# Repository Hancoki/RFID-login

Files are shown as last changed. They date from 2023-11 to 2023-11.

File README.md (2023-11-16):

# RFID-login

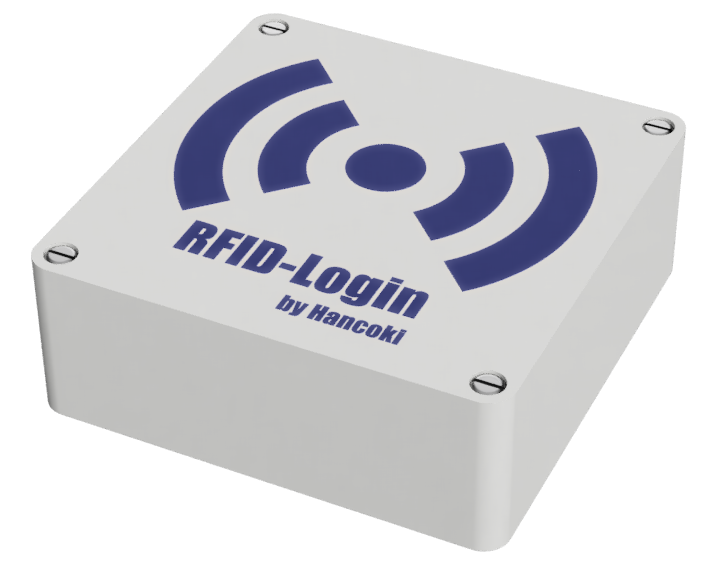
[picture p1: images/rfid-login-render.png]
RFID login render


## Description

This is a RFID login device based on the microcontroller [Sparkfun Pro Micro](https://github.com/sparkfun/Pro_Micro). It allows easy to type in your login credentials in same way as your keyboard does. But it seems a little bit smarter.

In first step I developed this device as a prototype on a breadboard. For the device I used the following components.

### Bill of material

- SparkFun Pro Micro 3.3V/8MHz microcontroller
- RFID MFRC522 reader & IC card
- circuit board size 70mm x 50mm
- USB mini cable (USB-A male/USB-B male) ~1m
- resistors 3x 200Ohm, 1x 100Ohm
- RGB led
- switch
- piezo buzzer

### Wiring

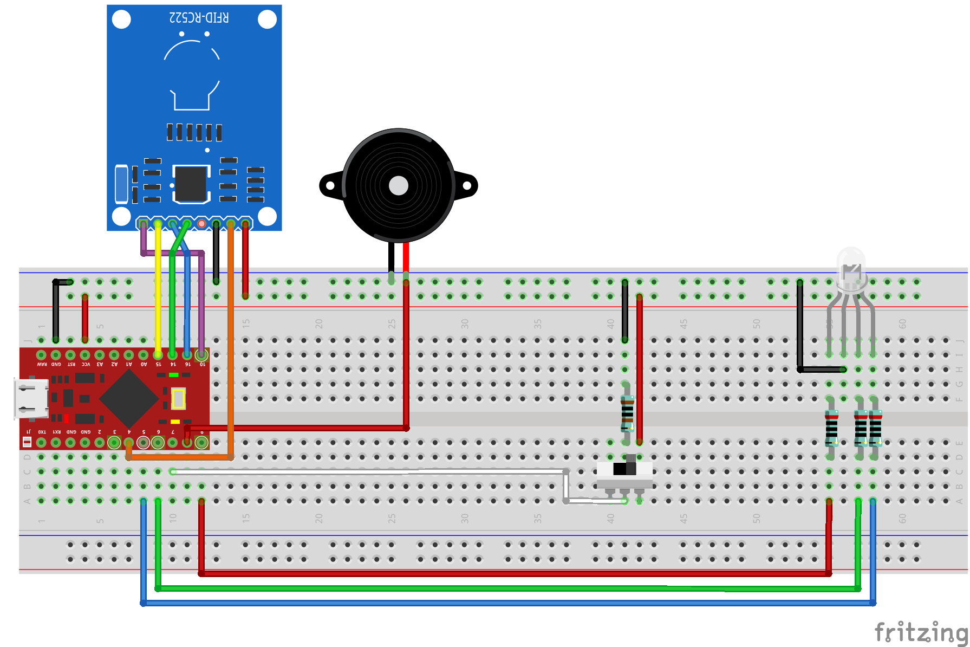
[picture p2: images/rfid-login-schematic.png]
RFID login schematic


As you can see in schematic above I wired the pins of microcontroller as follows:

Pin | Function      | Pin   | Function
--- | --------      | ---   | --------
4   | RST (RFID)    | 10    | SDA (RFID)
5   | LED (blue)    | 14    | MISO (RFID)
6   | LED (green)   | 15    | SCK (RFID)
7   | switch        | 16    | MOSI (RFID)
8   | buzzer        | GND   | GND
9   | LED (red)     | VCC   | 3.3V (RFID)

### Programming

For programming the Pro Micro I used [PlatformIO](https://github.com/platformio/platformio-core) inside of [VS CODE](https://github.com/microsoft/vscode).

Included libraries:
- [Keyboard library for Arduino](https://www.arduino.cc/reference/en/language/functions/usb/keyboard/)
- [Arduino library for MFRC522 by miguelbalboa](https://github.com/miguelbalboa/rfid)

## What comes next?

For a future version of my RFID login device I plan to decrement the size of case and develop a custom circuit board for it. Also a possibility to program the device instant without compiling the code again and again would be very nice.

If you have any questions or ideas for improvement, please let me know and write an issue.

Thanks for your participation!

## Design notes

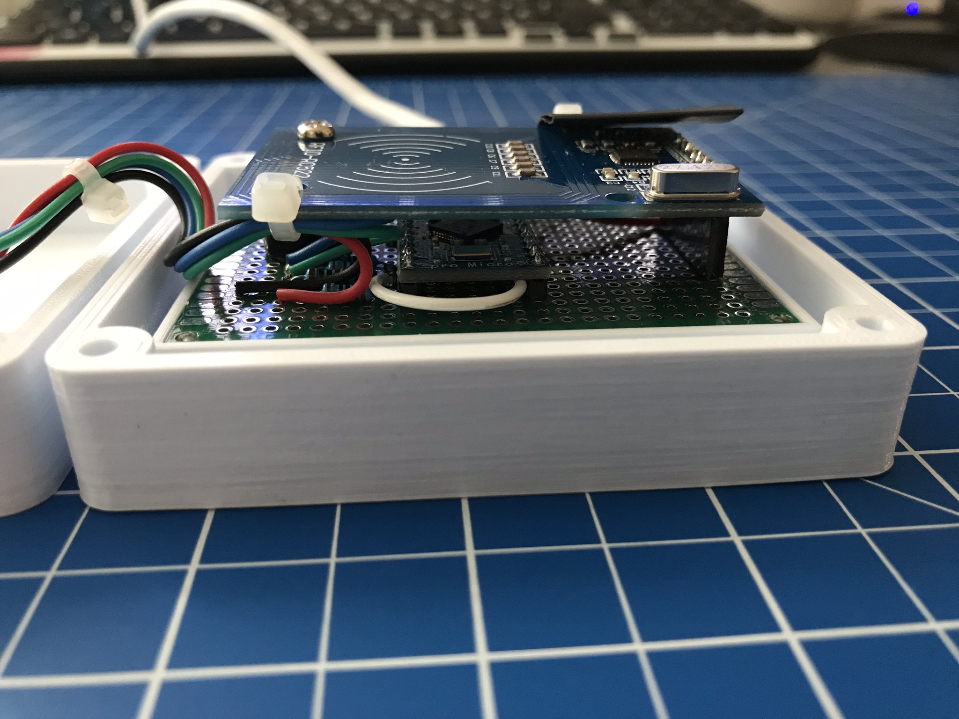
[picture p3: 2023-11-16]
images/rfid-login-prototype-sideview.jpg

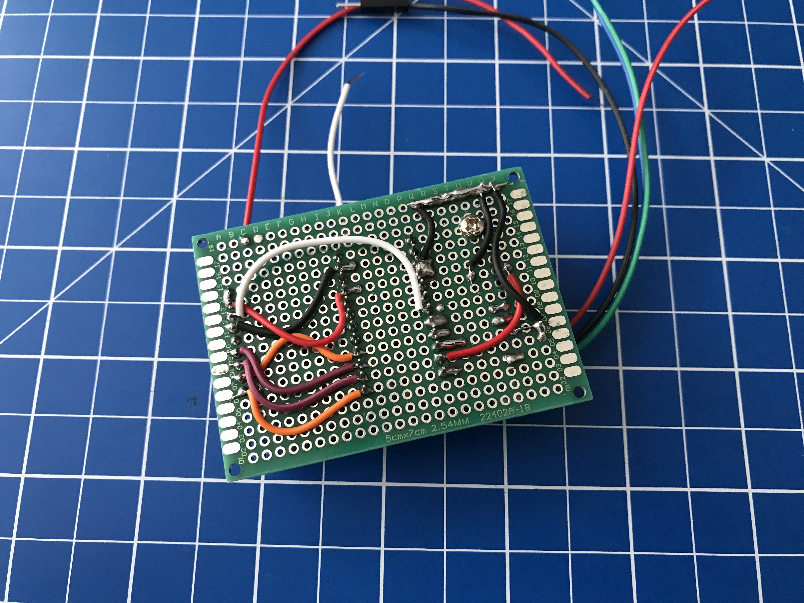
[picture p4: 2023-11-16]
images/rfid-login-prototype-circuit-board.jpg

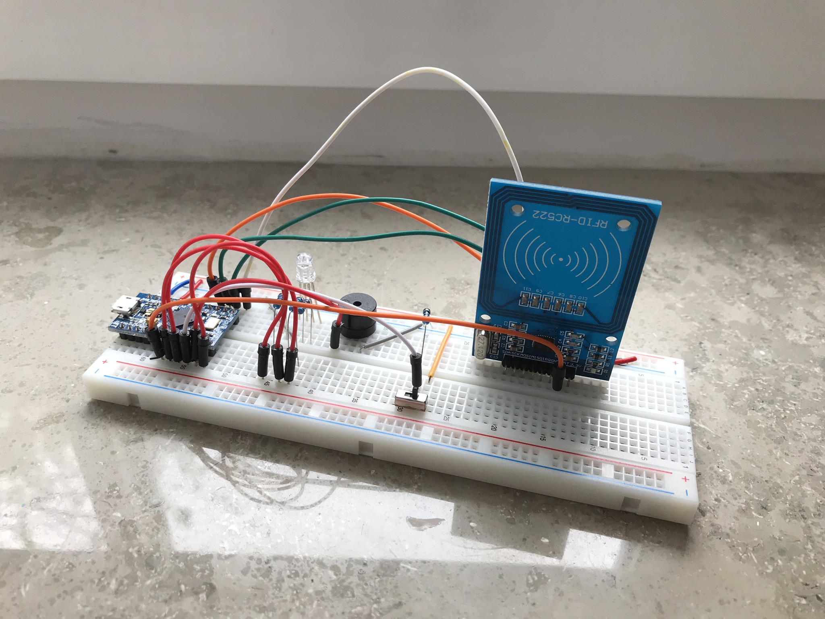
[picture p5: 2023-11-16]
images/rfid-login-prototype-breadboard.jpg

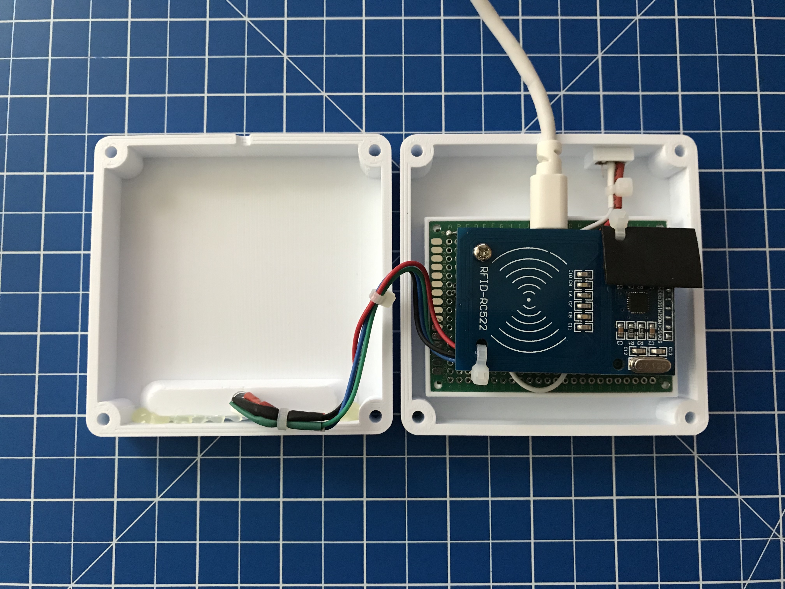
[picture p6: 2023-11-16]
images/rfid-login-prototype-final.jpg

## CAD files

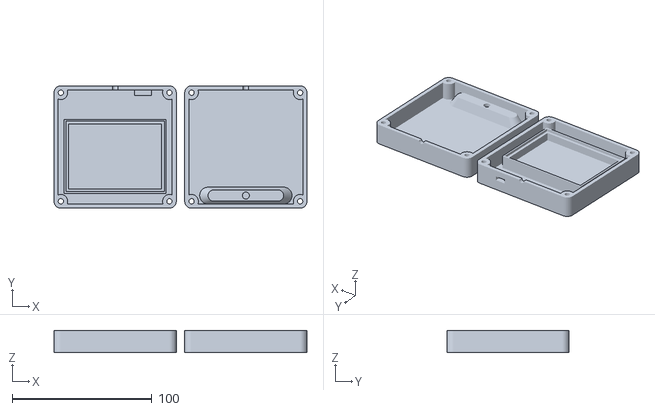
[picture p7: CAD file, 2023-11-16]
3d-files/case-complete.stl
180.8 x 87.4 x 16.0

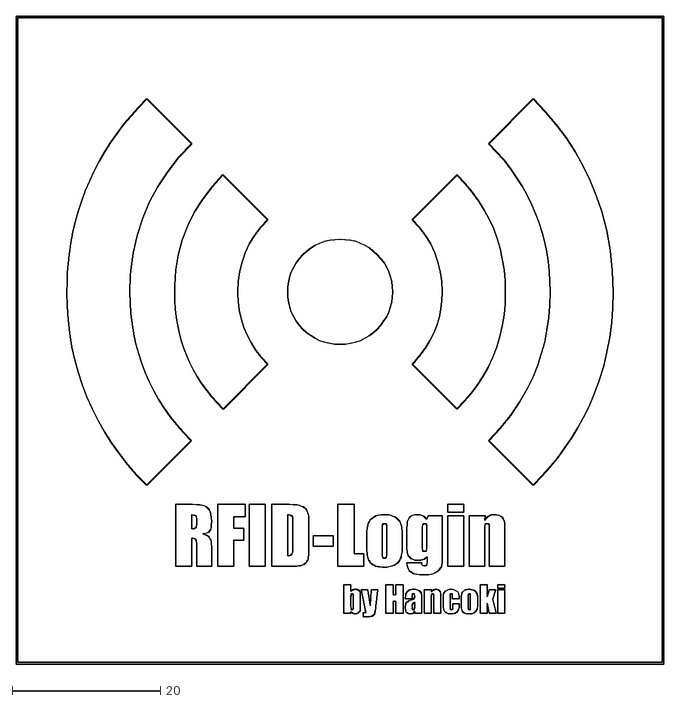
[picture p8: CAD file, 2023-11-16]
2d-files/case-label.dxf
87.4 x 87.4

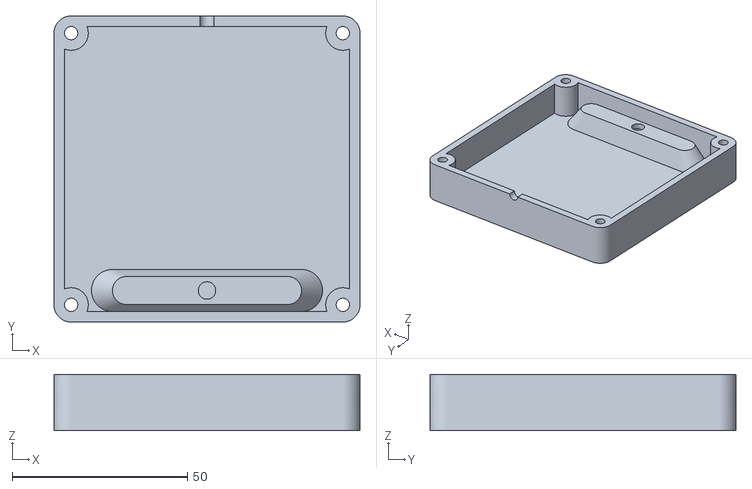
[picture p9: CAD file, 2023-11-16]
3d-files/case-top.stl
87.4 x 87.4 x 16.0

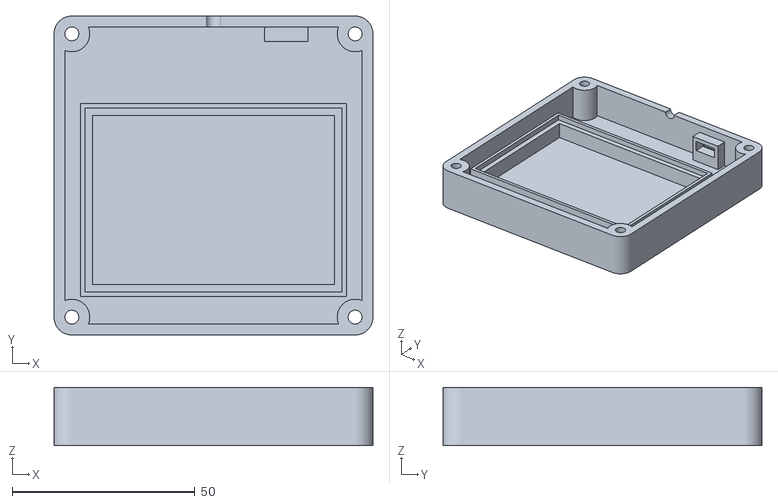
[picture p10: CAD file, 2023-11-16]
3d-files/case-bottom.stl
87.4 x 87.4 x 16.0

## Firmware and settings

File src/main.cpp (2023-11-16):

#include <Arduino.h>
#include <SPI.h>
#include <MFRC522.h>
#include <Keyboard.h>

#define LED_BLUE 5
#define LED_GREEN 6
#define SWITCH 7
#define BUZZER 8
#define LED_RED 9
#define SS_PIN 10
#define RST_PIN 4

const int DTIME = 500; // Delay for LED's

// Define your login credentials here, just for compiling 
const String password[] = {
  "test1",
  "test2"
  // [...]
};

// !!! WARNING: IT IS ABSOLUTELY NOT RECOMMENDED TO SAVE YOUR LOGIN CREDENTIALS IN SOURCE CODE !!!

// Define the UID's from your RFID tags here
const String tagUid[] = {
  "23011324848",
  "227181420"
  // [...]
};
 
String uidString = "";

bool rfidModeIsOn = false;
bool supportModeIsOn = false;

MFRC522 mfrc522(SS_PIN, RST_PIN); // Creating an instance of MFRC522

void grantAccess() {
  digitalWrite(LED_GREEN, HIGH);
  digitalWrite(BUZZER, HIGH);
  delay(DTIME/10);
  digitalWrite(BUZZER, LOW);
  delay(2*DTIME);
  digitalWrite(LED_GREEN, LOW);
}

void denyAccess() {
  digitalWrite(LED_RED, HIGH);
  for(byte i = 0; i < 3; i++) {
    digitalWrite(BUZZER, HIGH);
    delay(DTIME/10);
    digitalWrite(BUZZER, LOW);
    delay(DTIME/10);
  }
  delay(2*DTIME);
  digitalWrite(LED_RED, LOW);
}

bool readRfidTag() {
  if(mfrc522.PICC_IsNewCardPresent() && mfrc522.PICC_ReadCardSerial()) {  // Checking presence of RFID tag and a readable UID
    for(byte i = 0; i < mfrc522.uid.size; i++) {
      uidString.concat(mfrc522.uid.uidByte[i]);
    }
    mfrc522.PICC_HaltA();   // Go on halt to read the tag only one time
    return true;
  } else {
    return false;
  }
}

void activateSupportMode() {
  rfidModeIsOn = false;

  if(!supportModeIsOn) {   
    supportModeIsOn = true;
    digitalWrite(LED_BLUE, HIGH); 
    Serial.println("Welcome to maintenance mode! Here you can discover the UID's of your RFID tags.");
  }

  Keyboard.end();

  if(readRfidTag()) {  // If RFID tag reading success
    Serial.println("Your current UID is: " + uidString);
    uidString = "";
  }
}

void activateRfidMode() {
  supportModeIsOn = false;
  digitalWrite(LED_BLUE, LOW);

  if(!rfidModeIsOn) {
    rfidModeIsOn = true;
    for(byte i = 0; i < 2; i++) {
      digitalWrite(LED_GREEN, HIGH);
      delay(DTIME);
      digitalWrite(LED_GREEN, LOW);
      delay(DTIME);
      digitalWrite(LED_BLUE, HIGH);
      delay(DTIME);
      digitalWrite(LED_BLUE, LOW);
      delay(DTIME);
      digitalWrite(LED_RED, HIGH);
      delay(DTIME);
      digitalWrite(LED_RED, LOW);
      delay(DTIME);
    }
  }

  if(readRfidTag()) {  // If RFID tag reading success
    bool uidIsCorrect = false; 

    for(byte i = 0; i < sizeof(tagUid); i++) {
      if(uidString == tagUid[i]) {
        Keyboard.println(password[i]);
        uidIsCorrect = true;
      } 
    }

    if(uidIsCorrect) {
      grantAccess();
    } else {
      denyAccess();
    }

  uidString = "";
  }
}

void setup() {
  Serial.begin(9600); // Initialize interfaces
  SPI.begin();
  mfrc522.PCD_Init();
  Keyboard.begin();
  
  pinMode(LED_BLUE, OUTPUT);  // Setup IO pins
  pinMode(LED_GREEN, OUTPUT);
  pinMode(LED_RED, OUTPUT);
  pinMode(BUZZER, OUTPUT);
  pinMode(SWITCH, INPUT);
}

void loop() {
  if(digitalRead(SWITCH) == HIGH) { // Switch for activating the RFID mode
    activateRfidMode();
  } else {
    activateSupportMode();
  }
}

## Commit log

2023-11-16 Add STL files for printing
    [case-bottom.stl, case-complete.stl, case-top.stl]
2023-11-16 Add files for case label
    [case-label.dxf]
